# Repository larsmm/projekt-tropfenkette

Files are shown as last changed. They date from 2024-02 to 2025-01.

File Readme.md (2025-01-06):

# Welcome to Projekt Tropfenkette! ✨

A project featuring a box filled with 240 meters of ready-to-use LED strips to make events more colorful. These boxes are stored in hackerspaces or at the homes of beings. Coordination of which boxes are used at which events is done through a [Matrix group](https://matrix.to/#/#projekt-tropfenkette:matrix.warpzone.ms).

<table><tr>
<td><a href="https://www.youtube.com/watch?v=VafaI8VTRTc" target=new>My talk about this project at KampHack 2024 in warpzone hackerspace in Münster</a><br>
    <em>My talk about this project at <a href="https://kamphack.de/" target=new>KampHack 2024</a> in <a href="https://www.warpzone.ms/" target=new>warpzone</a> hackerspace in Münster (in german)</em></td>
</tr></table>

<br />

<table>

<tr>
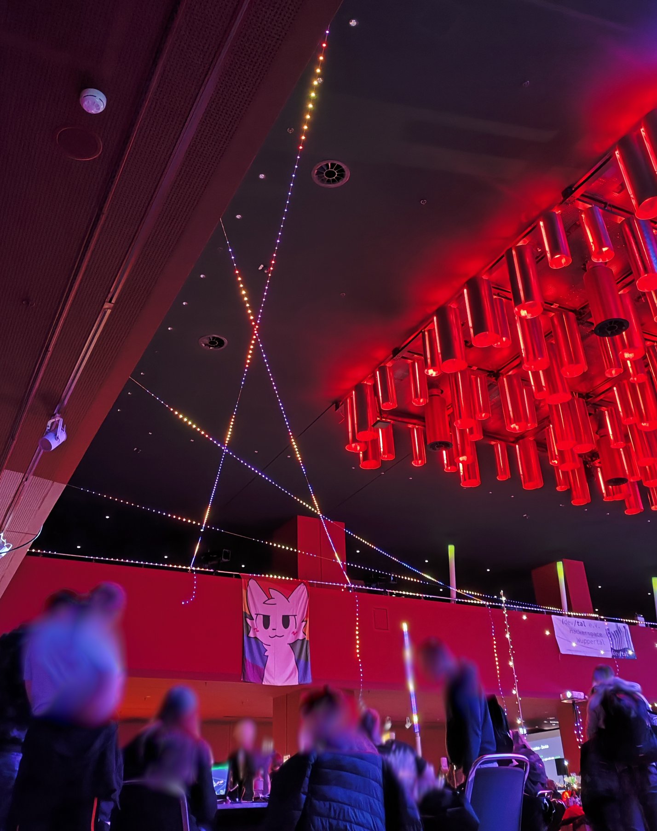
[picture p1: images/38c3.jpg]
<td> <a href="images/38c3.jpg"></a> </td>
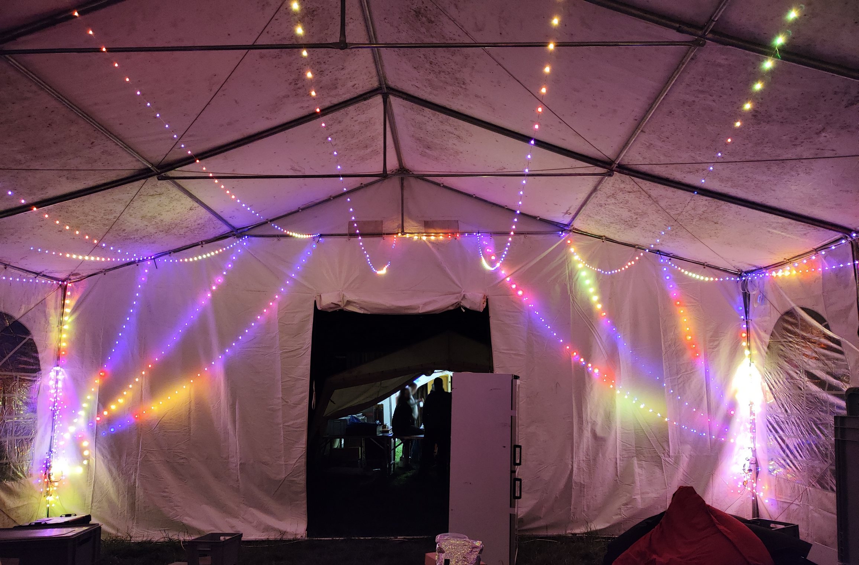
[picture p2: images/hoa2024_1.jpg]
<td>  </td>
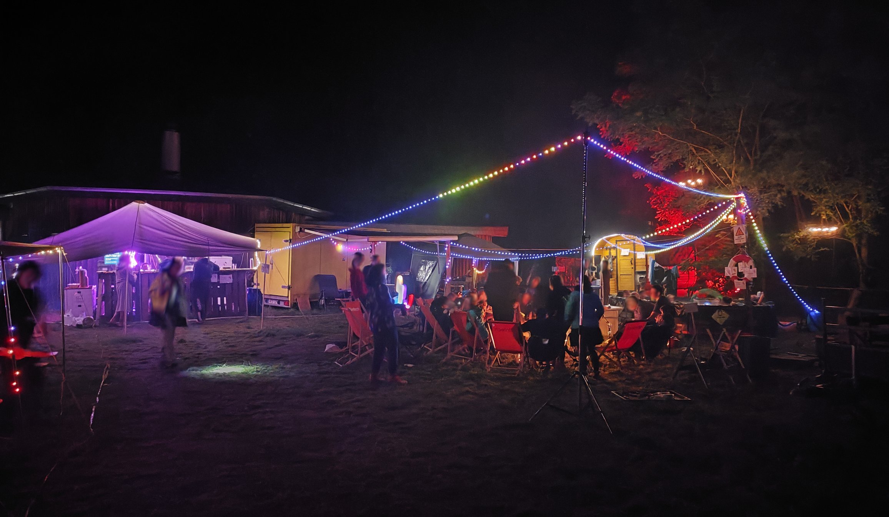
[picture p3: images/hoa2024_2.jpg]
<td>  </td>
</tr>

<tr>
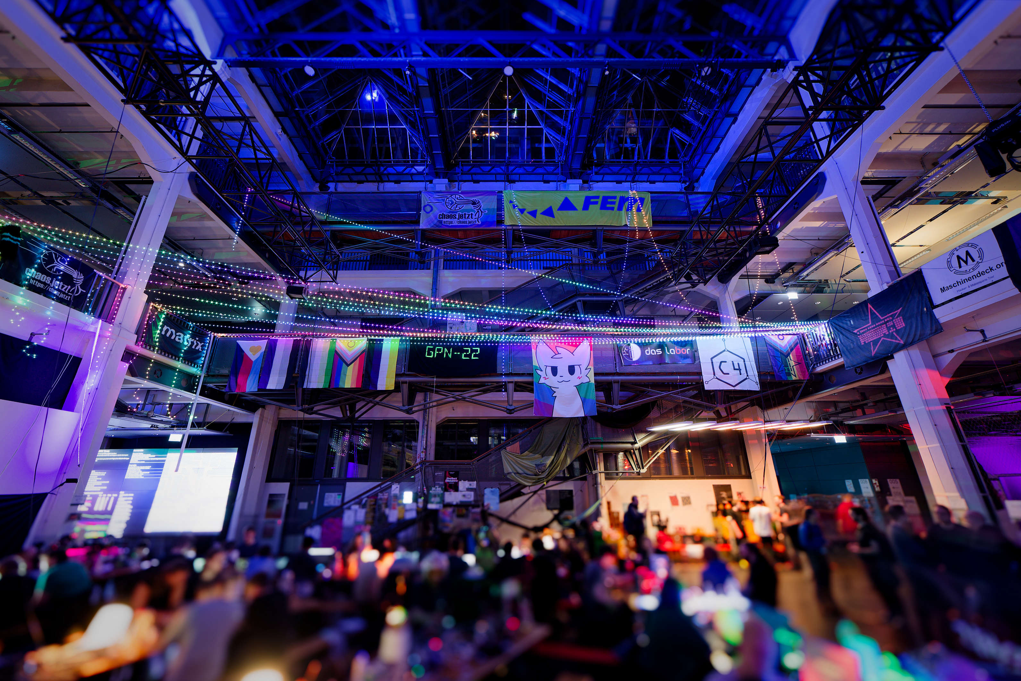
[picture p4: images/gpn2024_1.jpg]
<td>  </td>
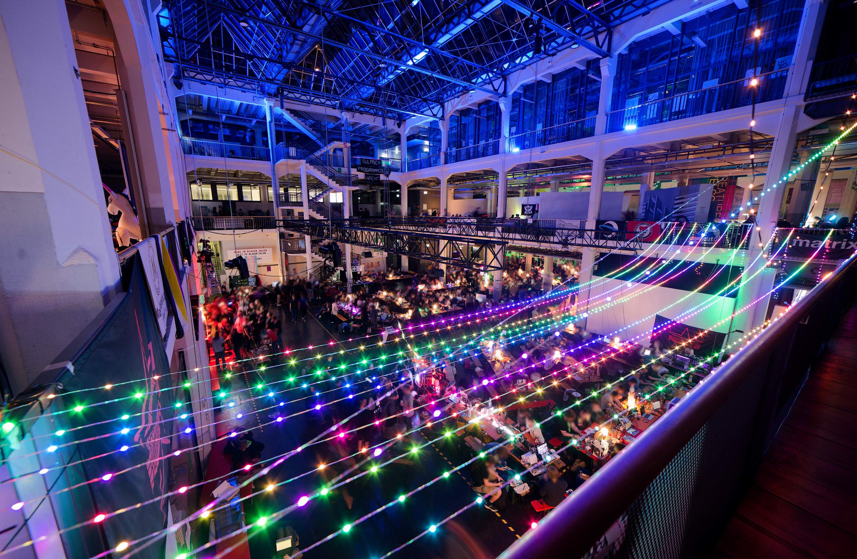
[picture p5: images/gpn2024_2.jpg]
<td>  </td>
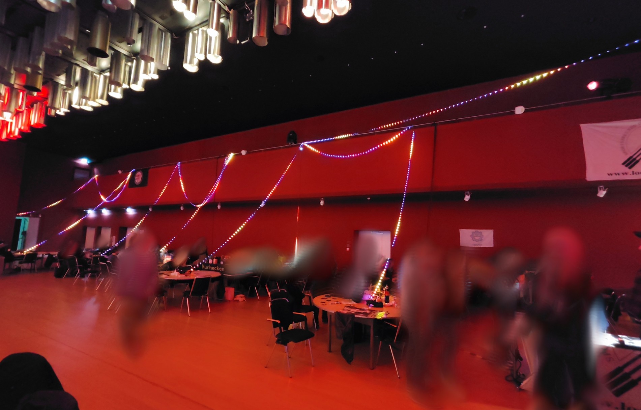
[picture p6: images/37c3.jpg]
<td>  </td>
</tr>

<tr>
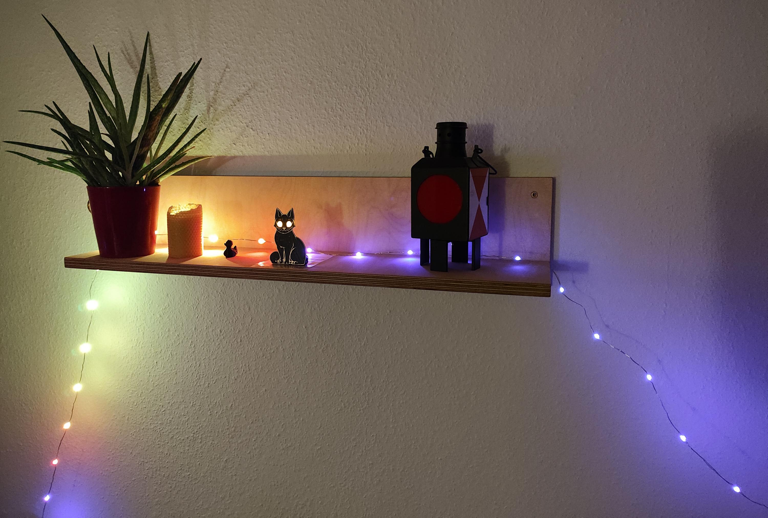
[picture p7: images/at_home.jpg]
<td>  </td>
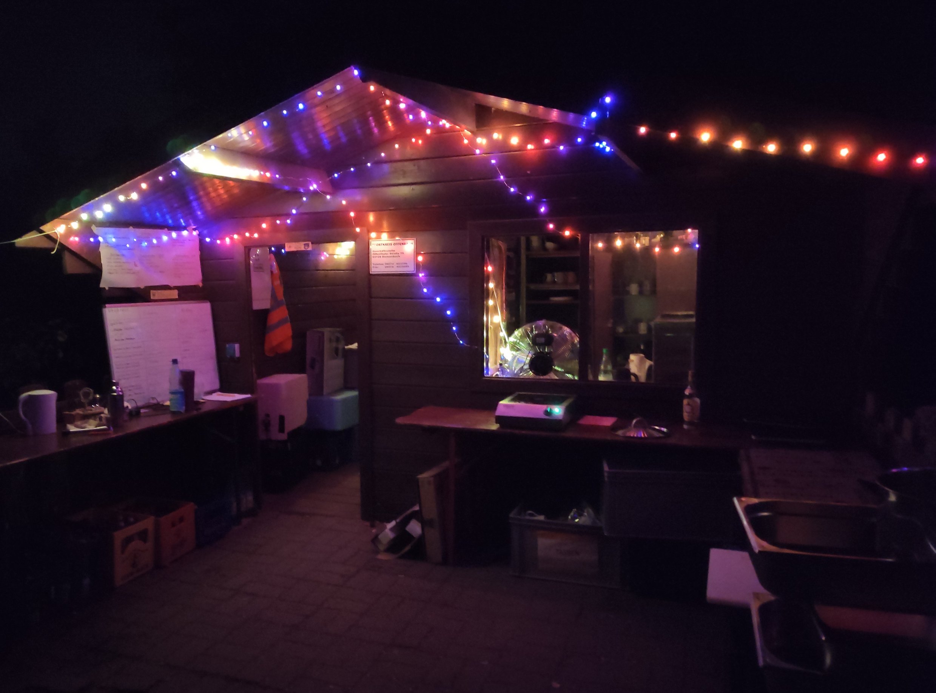
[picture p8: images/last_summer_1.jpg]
<td>  </td>
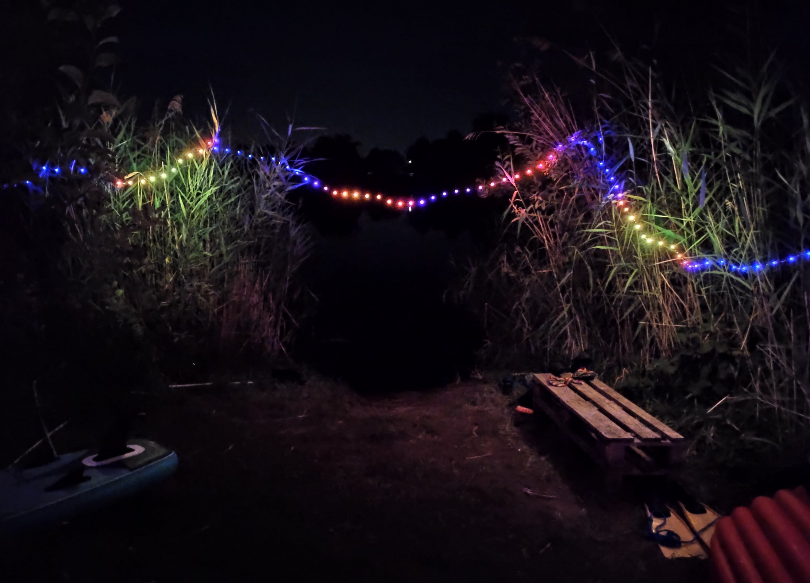
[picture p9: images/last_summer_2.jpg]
<td>  </td>
</tr>

<tr>
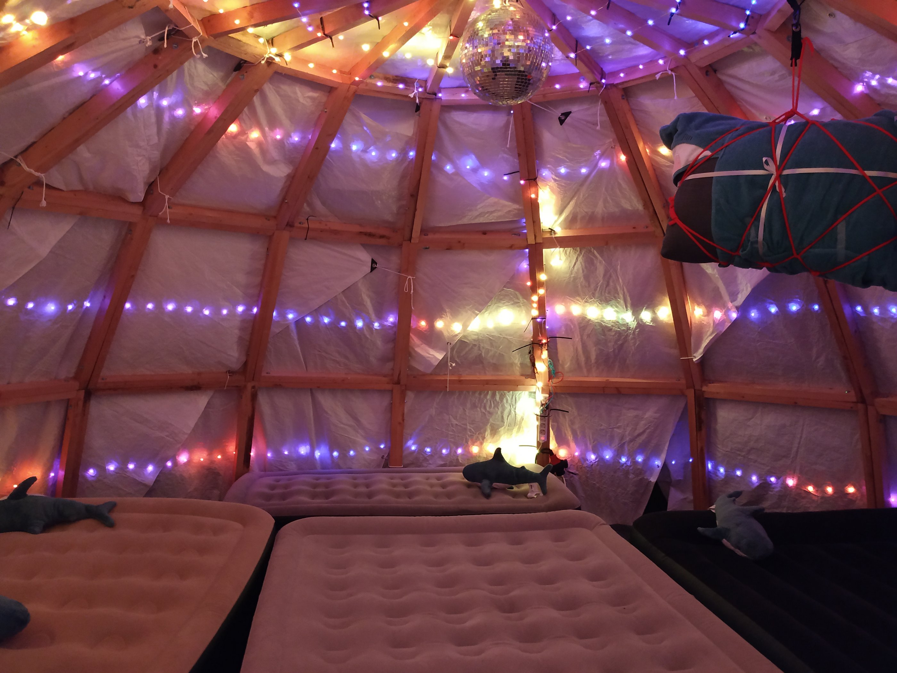
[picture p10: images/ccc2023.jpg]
<td>  </td>
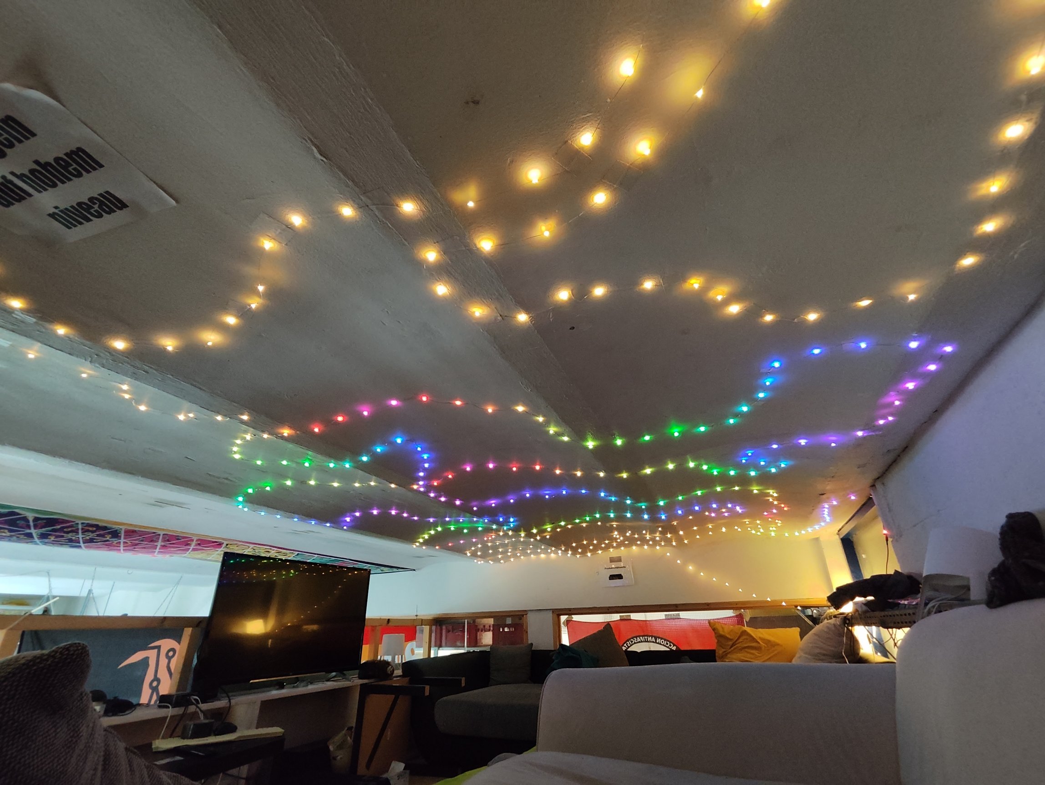
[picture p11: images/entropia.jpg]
<td>  </td>
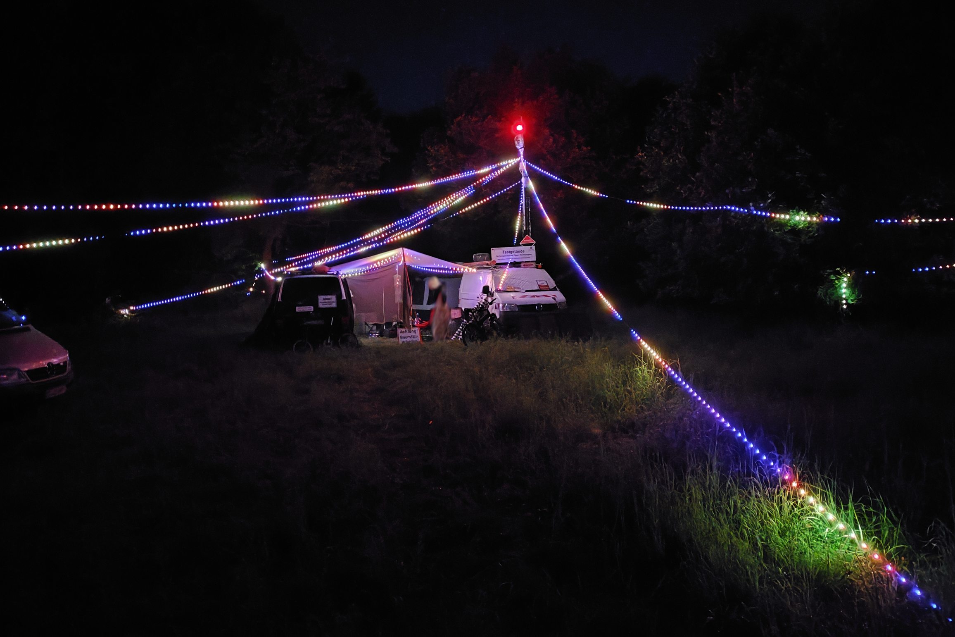
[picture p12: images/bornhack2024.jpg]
<td>  </td>
</tr>

<tr>
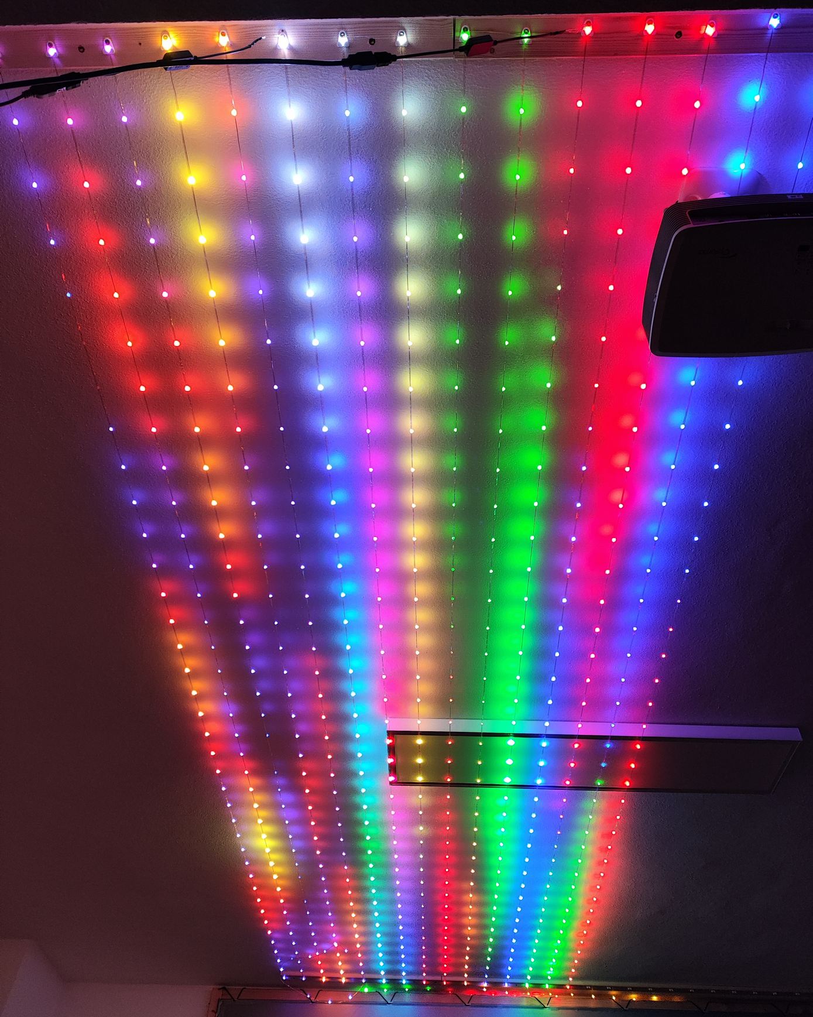
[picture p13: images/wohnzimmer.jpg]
<td> <a href="images/wohnzimmer.jpg"></a> </td>
<td>  </td>
<td>  </td>
</tr>

</table>

## Features

- Euro-box dimensions: 30 x 40 x 23 cm (or slightly smaller)
- 20m spools of LED Tropfenkette with 200 addressable RGB LEDs each + USB power supplies
- 3D-printed spools compatible with a power drill adapter
- WLED firmware on an ESP32 microcontroller
- User-friendly web interface
- WiFi and optional Ethernet with PoE support
- All information, instructions, and a service manual available in this Git repository
- A label on the box providing links to this Git repository and the [Matrix group](https://matrix.to/#/#projekt-tropfenkette:matrix.warpzone.ms)
- Each piece is labeled with a "Project Tropfenkette" sticker
- A [Matrix group](https://matrix.to/#/#projekt-tropfenkette:matrix.warpzone.ms) for coordinating the use of the boxes

## Contents of Each Box

<table><tr>
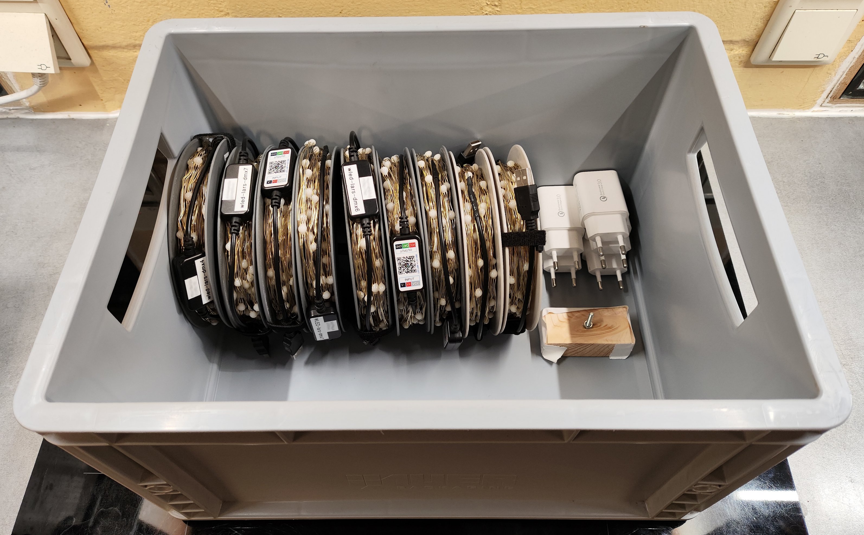
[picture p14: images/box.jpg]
<td>  </td>
</tr></table>

- 12 LED spools
- 12 WLED controllers
- 18 USB power supplies (to power some strips from both ends)
- 2 power drill adapters
- A bag of reusable cable ties
- 6 hook magnets (maybe)
- 2 spare controllers
- 2 empty spare spools
- Project Tropfenkette stickers
- A rubber duck

## LED Strip

20m long LED strips, available [here](https://www.aliexpress.com/item/1005003243510750.html), consisting of an addressable LED every 10cm on 3x magnet wire (enameled copper wire). Reasons why I really love these LEDs:

- Very high, not visible PWM frequency (non-flickering). Even when moving very fast in front of your eyes, it appears as a single line.
- Very good and intense colors, including a nice RGB-mixed white.
- Good omnidirectional light distribution.
- Very low idle current of 0.0125mA/LED, compared to other LEDs that need ~1mA.
- High ESD stability.

A disadvantage is the low mechanical durability due to being made of single stranded, thin insulated wires. However, with careful handling, they last many events and are quite easy to repair.

For most WLED effects, powering them from one side is sufficient. Plugs on both ends allow optional dual-side power. However, their brightness when powered from one side is moderate. For illumination purposes, you might need many strips or alternative solutions. Their true strength lies in creating a pleasant ambiance.

The strips are lightweight, enabling easy horizontal suspension over distances of 20m or 40m when connecting two strips end-to-end.

### Water Resistance

The strips are somewhat water-resistant. Exposure to rain or damp grass poses no issue. However, submersion beyond of more than ~3m of ledstrip may lead to erratic behavior due to high capacitance (as tested in a pool).

### Hardcoded Addresses

Unlike on most other strips, these LEDs are all connected in parallel, so each LED gets the same signal. That means, every LED has a hardcoded address. The low idle-current is a benefit of this. However, this means strips cannot be serially chained without duplicating control signals. For instance, if you connect two 200 LED strips in series, you still have the address range 1-200 instead of 1-400. If you activate one LED, the corresponding LEDs on both strips will light up. This requires careful planning for specific lighting designs. In this project, enery strip gets its own microcontroller pin.

## The Spool

The spool for winding the strip is 3D printed ([STL 1](stl/spool-1.stl), [STL 2](stl/spool-2.stl)) in two halves and then glued together. Currently, a simple wooden piece with an M5 screw serves as a makeshift power drill adapter. A 3D printed version has to be designed.

<table><tr>
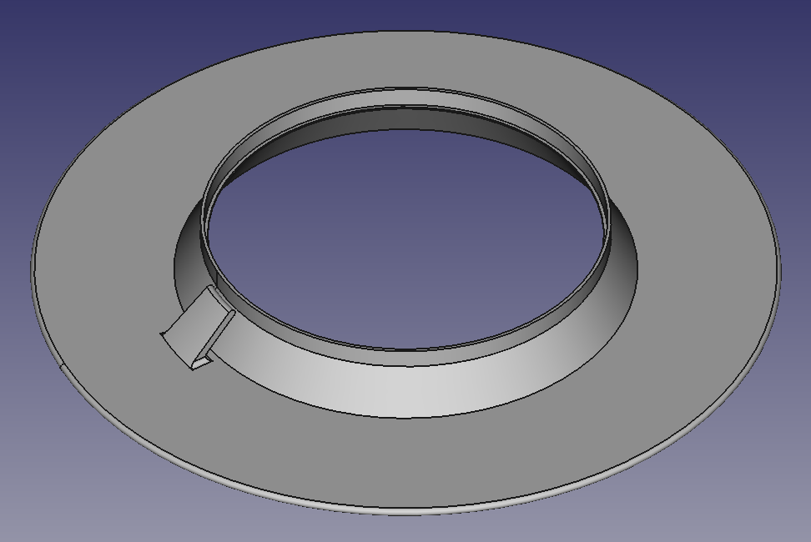
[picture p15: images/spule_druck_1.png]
<td>  </td>
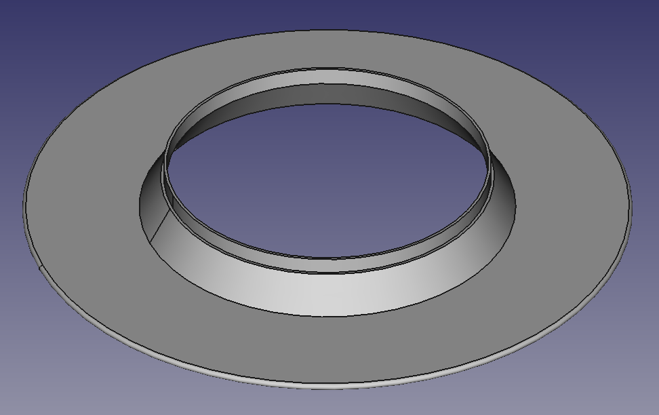
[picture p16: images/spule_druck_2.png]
<td>  </td>
</tr></table>
<table><tr>
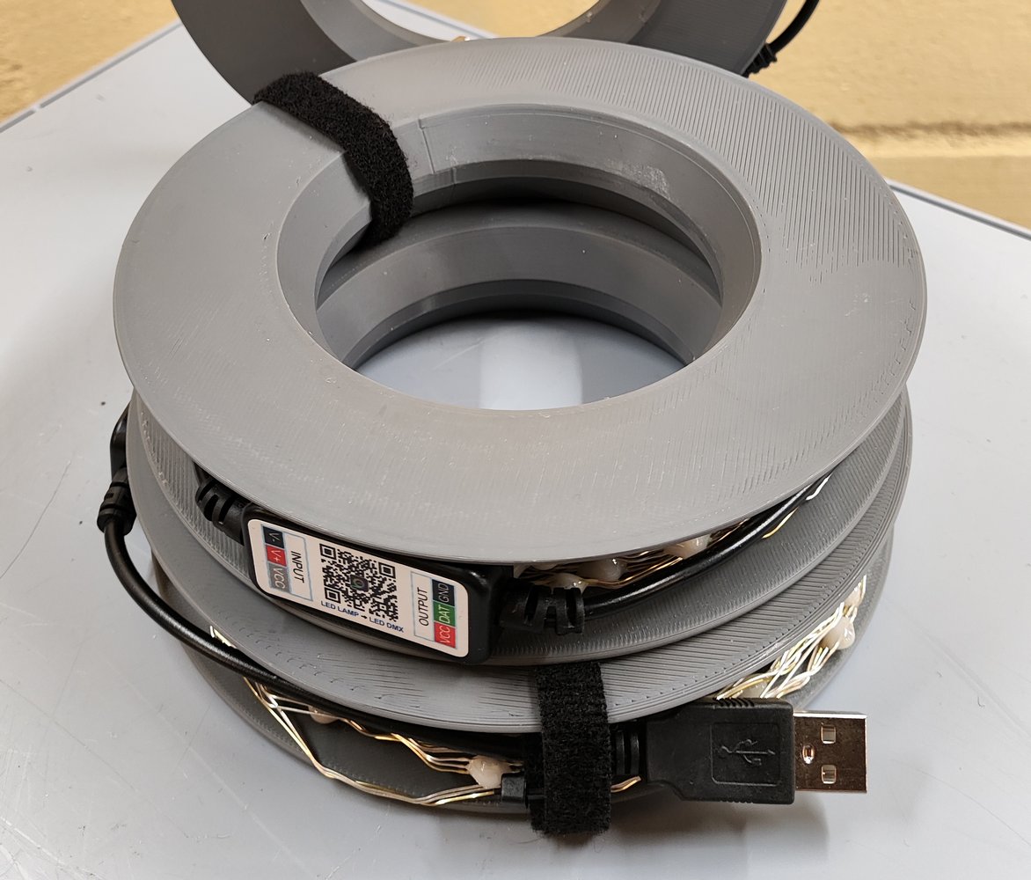
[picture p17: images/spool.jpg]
<td>  </td>
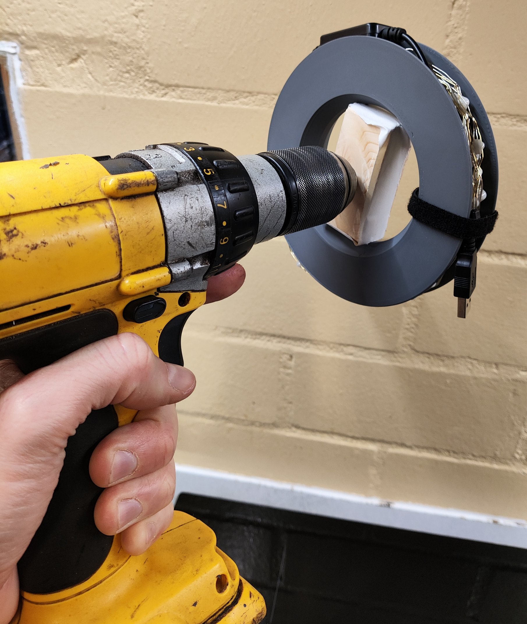
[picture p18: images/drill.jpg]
<td>  </td>
</tr></table>

## USB Power Supply

A simple 5V 3A [USB power supply](https://www.amazon.de/Ladeger%C3%A4t-Schnellladeger%C3%A4t-Ladestecker-Netzteil-Schnellladung-4er-Pack-Schwarz/dp/B0C3B7FL8Z). We tested (secutest) a few of them; they were safe. The power is sufficient, even if there is no current limit set in WLED. The wire resistance limits the current to ~2.3A.

## The Simple Controller with Standard Components

<table><tr>
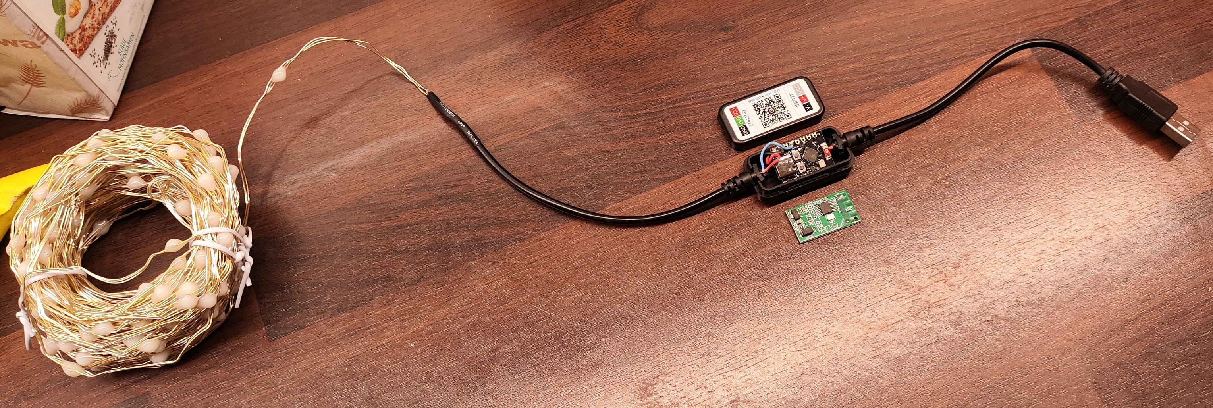
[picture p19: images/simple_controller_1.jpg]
<td>  </td>
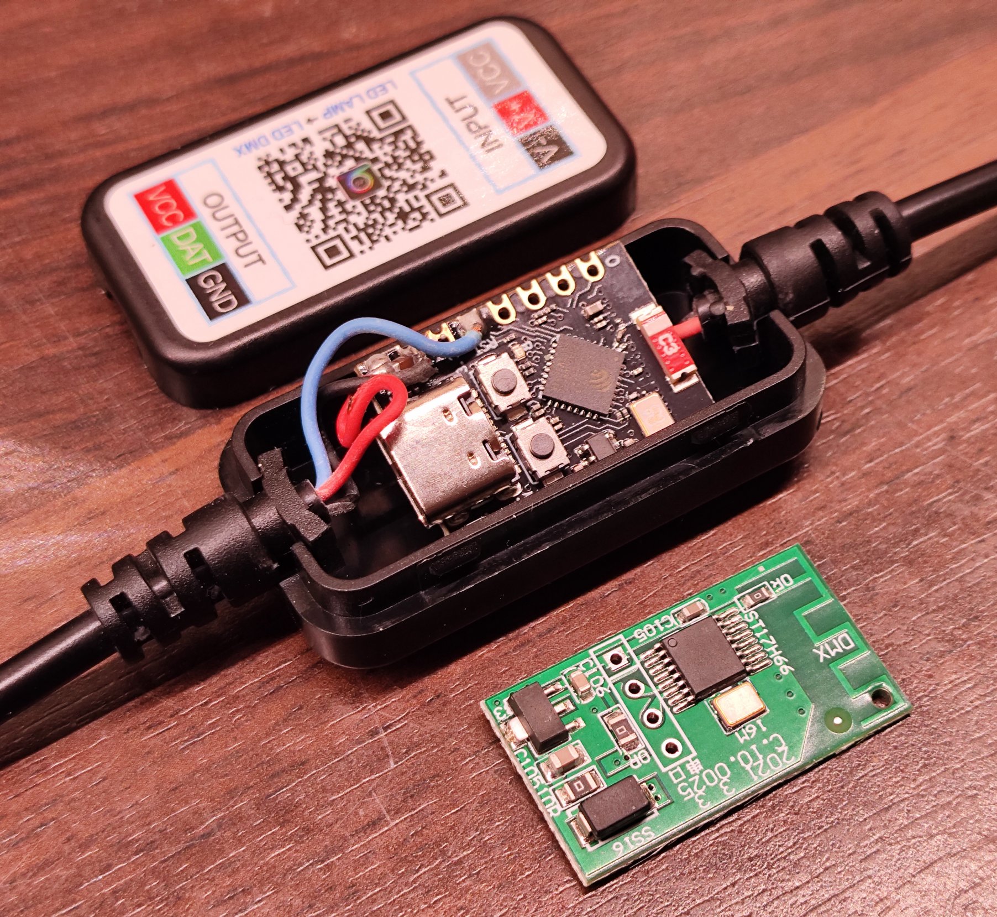
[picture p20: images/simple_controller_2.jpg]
<td>  </td>
</tr></table>

Ready to use [ESP32-C3-board](https://www.aliexpress.com/item/1005005967641936.html) with USB-C from AliExpress. Every 20m LED strip gets its own controller for convenience and because of the maximum current. The LED strips are shipped with a proprietary bluetooth controller, which gets replaced by our WLED controllers.

<table><tr>
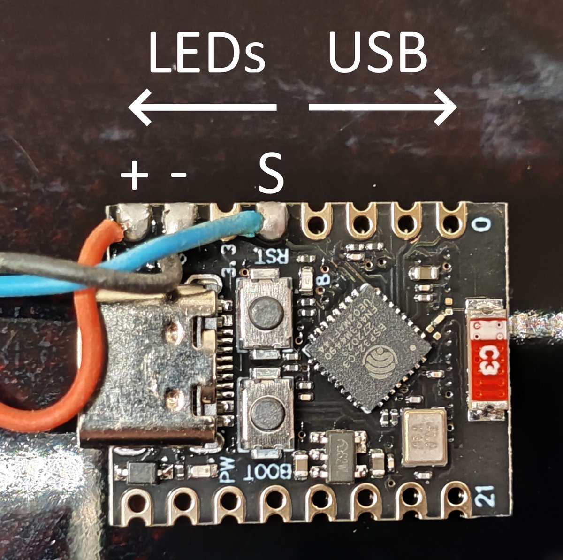
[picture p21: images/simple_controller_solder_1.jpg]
<td>  </td>
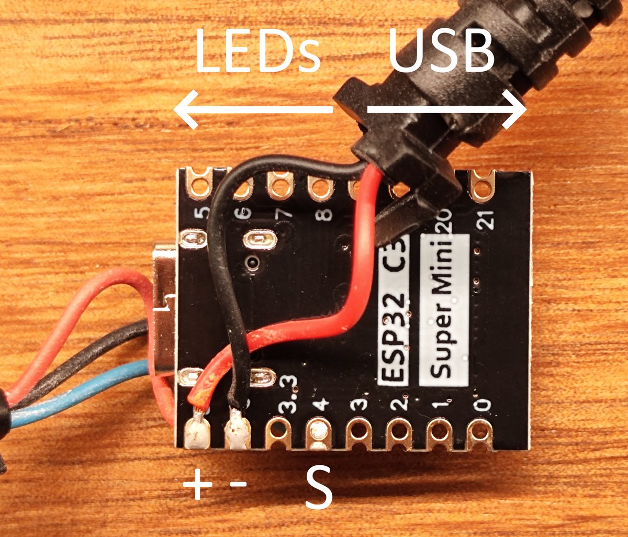
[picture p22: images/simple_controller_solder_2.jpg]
<td>  </td>
</tr></table>

How to solder:

- Open the case and unsolder the Bluetooth controller.
- Touch the wire ends of the LEDs with your soldering iron to make them pointy.
- Clamp the board somewhere, but be careful not to destroy the very small SMD parts.
- Put the 3 wires coming from the LEDs through the holes in the board and solder them with a bit of solder wire.
- Then solder the 2 USB-wires to the back of the board. Make sure to heat them up enough to get a good connection and short enough to not unsolder the LED-wires. The soldering points should be quite flat to fit into the case.

## Software

The strips are controlled by [WLED](https://kno.wled.ge/), firmware with many input options and a web interface to easily create nice effects. There are two common websites to flash WLED:

- The official one: <https://install.wled.me/> (Usually we use the newest build from here)
- And the fancy one: <https://wled-install.github.io/> (If you want more fancy features, use the nightly build)

Flash:

- Open the case and connect the ESP-Board via USB-C port, the USB-A plug is not for flashing!
- Open flash-page in a web-uart capable browser like chrome, choose the com port and the newest build of WLED.

Configuration:

- After flashing, connect to the `WLED-AP` Wifi. The landing page should open automatically. If not, enter <http://4.3.2.1> in your browser.
- TO THE CONTROLS! > Config > Security & Updates >
  - Restore presets: [choose file](cfg/wled_presets.json) > Upload
  - Restore configuration: [choose file](cfg/wled_cfg.json) > Upload
- The ESP will restart now. Now connect to Wifi again:
- WIFI SETTINGS > AP SSID: `WLED-[your name]-tk[number]`. For example `WLED-larsm-tk1`. Also write this name onto the controller-case.
- If you want to put the strips into an existing Wifi you can do so in Wifi Settings.
- The current limit in `LED Preferences` is not set because the wire resistance is limiting the current enough. Also, different limits were needed whether powering from one or both ends. It may result in strange looking effects by missing colors at the not powered end of the strip. Lower the brightness of the effect until it is ok.

### Default effect

WLED comes with many different effects and color schemes. The default effect is `Plasma` and the default color scheme is `Yelblu Hot` on full brightness. This is saved on Preset no 1 and loaded on boot. It is a slow, cosy effect using mostly yellow and orange but also a bit blue and purple. It sums up to a candle-like very warm white.

### Wifi name and PW

The SSID is printed on each controller-case `WLED-larsm-tk1`. The default PW is `wled1234`. This is a widely known PW. Please do only change it for a good reason and change it back after usage.

## Usage Guide

### Coordination

Utilize the [Matrix group](https://matrix.to/#/#projekt-tropfenkette:matrix.warpzone.ms) for coordination with hosts of other boxes. Ask them to bring boxes or offer your box.

For events involving larger installations, it's crucial to consult with the event organizers regarding **fire safety regulations (Brandschutz)** and **emergency exit routes (Fluchtwege)**.

### Use Cases

Choose your level of complexity:

1. **Simple Setup**: Unroll a few strips and power them via USB to enjoy the nice default effect.

2. **Intermediate**: Optionally, connect to the Wi-Fi printed on each controller (default password: `wled1234`). Access the web interface at <http://4.3.2.1> to customize effects.

3. **Advanced Synchronization**: WLED features an easy-to-use function for syncing effects across multiple controllers. Ensure they're connected to the same network via Wi-Fi or Ethernet.

4. **Professional-Level Control**: For granular control over every pixel across numerous strips in real-time, consider using Streaming ACN (sACN) over Ethernet.

## Help!!11!

**LED-strip broken:** please solder and insulate broken wires, ask for help in your local hackerspace and drink a mate.

**Controller broken:** Things you can try: connect to wifi, connect no or another ledstrip, reflash the controller. Use a multimeter and check voltages and currents.

**Something needs to be replaced or got lost:** It would be nice to keep this project alive by the awesome hacking community. So donations of replacement parts would be very welcome. If you, your fellow hackers or your hackerspace cannot afford it, please contact the [Matrix group](https://matrix.to/#/#projekt-tropfenkette:matrix.warpzone.ms).

## Two types of LEDs are sold :-(

These strips are sold with 2 kinds of LEDs on aliexpress which look the same on photos but with huge quality differences. Here a comparison:

| | Good strip | Bad strip |
|---|---|---|
| Protocol | default 3 wire WS28* | default 3 wire WS28* |
| LED type | custom nameless LED without extra plastic case within the glue drop | default WS2812B LED, you can see the quadratic case within the glue drop |
| PWM-frequency | very high == invisible | ~1-2Khz == flickering |
| Omnidirectional light distribution | noticeable but quite good | very noticeable |
| Quality of colors | nice | a bit less intense |
| Quality of RGB-mixed white | clean and nice white | unpleasant red tinge |
| Interconnection on the wires | parallel, each LED gehts the same signal, each LED has a hardcoded address | serial, default WS2812B LED with signal amplifier in each LED |
| Color of the wire (insolation) | a bit more copper-like | a bit more silver-like (not a huge difference, hard to tell on photos) |
| Idle-current [mA/LED] | 0,0125 | 0,50 |
| Current, white 50% [mA/LED] | 18,25 | 24,77 |
| Current, white 100% [mA/LED] | 35,45 | 42,93 |
| Digital color-order | RGB | GRB |
| Brightness | is hard to tell without measuring it | |
| Price | quite equal | |

So how to buy the good ones? There are a couple of dealers on aliexpress selling them. A good approach is to maintain a list of dealers and their offers, along with records of successful and unsuccessful purchases:

| good or bad | known good order | known bad order | Dealer | link | comment |
|---|---|---|---|---|---|
| ✅? | ~2023-11-20 | - | Aurboos LED Strip Store | [link](https://de.aliexpress.com/item/1005004753971048.html)  | Type: "Copper Wire"! The last known good order was quite a while ago. It's unclear if the good strip is still being delivered. Additionally, it has been out of stock for weeks. |
| ❌ | 2024-03-15 | 2024-06-03 | Mi Light Store | [link](https://www.aliexpress.com/item/1005003243510750.html) | It was a good source for a long time, but not anymore. I contacted the dealer. He said he could deliver the good strips, send me a test strip which was the bad one. :'( |
| ❌ | - | 2023-10-13 | LOAMLIN Official Store  | [link](https://www.aliexpress.com/item/1005001917228863.html) | Seller wrote 2023-11-14: the good ones are no longer available. |

As long as the strips are unavailible in Aurboos LED Strip Store the only source is Mi Light Store which is selling the bad strips. Don't get me wrong, but they are still good LED strips. I'm just very demanding.

Another thing: when ordering a 20m strip, you always get 2 10m pieces that are soldered together in the middle. In one delivery of the otherwise good strips, they were incorrectly addressed, namely 1-100 + 1-100 or 1-100 + 100-1 instead of 1-99 + 100-200. However, this only happened with one of many orders. Please test this upon arrival.

If something is not right, it is now very straightforward to return it on AliExpress. Simply click in the order overview, receive a shipping label, send it to a German address, and receive the refund within about a week.

## Bill of Materials - BOM

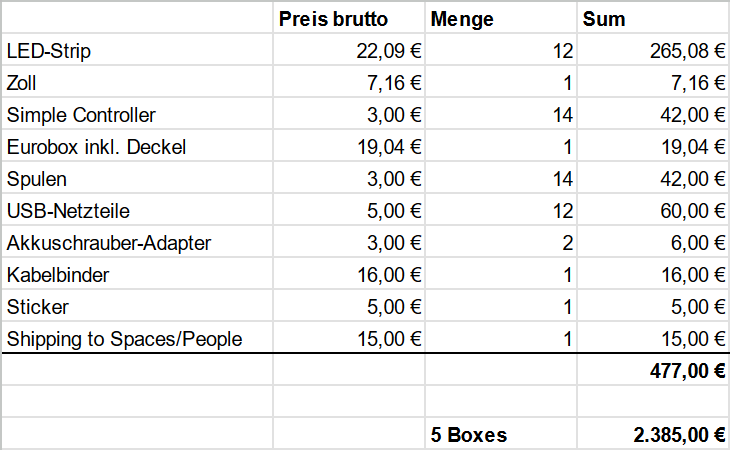
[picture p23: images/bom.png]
BOM (https://docs.google.com/spreadsheets/d/1PHROypnwYwpfAeiwreOVh2BaQhaZet9fSIjJTCfw_kE)


## The funding

The project, consisting of 5 boxes, is hoped to be financed by the CCC. For more details, refer to the [Projektantrag](Projektantrag.md).

## Vision

I would really love to see a lot of these LEDs on many future events! It would be great to see nearly all of them illuminating on next congress! :D

### The Advanced Controller with Custom Board

Vision: Custom WLED PCB with ESP32, microphone, and PoE. It can be used standalone or controlled via WiFi and powered by USB-C, or controlled and powered by Ethernet. If powered with more than USB 5V, more than 1 strip can be connected to 1 controller. Use the button on the PCB to switch through effects. I have already found some nice people who are definitely able to design this PCB, and they are hopefully willing to do it. :-)

### Microphone-Box

Vision: A small 3d-printed box with an [ESP32 board and a microphone](https://github.com/NandXor96/USBWLEDC) inside without LEDs. It can be used to control the audioreactive effects on the Tropfenketten. The network latency is quite high in WLED 0.15. We should wait for improvements.

### Other types of LEDs

Vision: Maybe the project will grow and other types of LEDfoo will spawn. For example the 2m long pipes wrapped with LED-Strip as seen on 37C3.

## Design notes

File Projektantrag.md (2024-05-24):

# Projektantrag zu Project Tropfenkette

Lieber CCC,

hiermit stelle ich einen Projektantrag für adressierbare RGB-LED-Lichterketten-Sets für chaosnahe Events. Jeweils 20m dieser Tropfenkette sind auf einer 3D gedruckten Spule aufgewickelt. 12 Spulen inkl. WLED-Controllern, Netzteilen und Montagematerial sind in einer Box zusammengefasst. Die Boxen werden in Hackspaces und deren Umfeld verteilt. Durch eine Matrix-Gruppe bleiben die Box-Holder in Kontakt und koordinieren den Einsatz auf Events. [Dieses GIT](Readme.md) bietet alle Informationen zur Nutzung und Instanthaltung des Projektes.

Einen Prototyp einer solchen Box war schon auf vielen Events im Einsatz, wo ich viel positives Feedback erhalten habe. Die bisher größten Installationen mit 200m waren auf dem 37C3 in einem der Hackcenter und auf der Esterhegg 2024 mit 320m. Um es größer zu skalieren, ist die Community gefragt, was ich in diesem Projektantrag verwirklichen möchte. Einige Wesen der warpzone in Münster und aus anderen Spaces konnte ich bereits für das Projekt begeistern und sie haben Hilfe angeboten.

Ich habe mit vielen Menschen aus dem Chaos über das Projekt gesprochen und viele Ideen mit einfließen lassen. Darunter auch Menschen, die etwas von Veranstaltungstechnik verstehen, Team Power und einigen Orga-Wesen auf dem 37C3. Ich habe Themen, wie Brandschutz, Fluchtwege und Sicherheit angesprochen. Solange man die Ketten nicht quer durch Fluchtwege hängt, gab es keine Bedenken. Auch elektrisch sind sie sicher, da sie nur mit 5V betrieben werden.

## Finanzierung

Die Kosten für eine Kiste belaufen sich auf ca. 480€, siehe [BOM](https://docs.google.com/spreadsheets/d/1PHROypnwYwpfAeiwreOVh2BaQhaZet9fSIjJTCfw_kE). Ggf lassen sich Rabatte nutzen, ggf ändern sich Preise und es wird teurer. Ich würde zur Sicherheit also 500€ pro Box einplanen. Ich würde mir wünschen, dass der CCC das Projekt finanziert. Die Anzahl der Kisten kann natürlich variiert werden.

## Umsetzung

Die Umsetzung bedeutet eine Menge Arbeit. Das Material muss bestellt, Spulen gedruckt, Controller gelötet, Firmware geflashed und Labels gedruckt werden, ...

### Bestellung

Das Meiste muss bei Aliexpress bestellt werden, ein Teil aus Deutschland. Vorschlag: Der CCC überweist mir einen Vorschuss von z. B. 2000€, ich tätige die Bestellungen. Wahrscheinlich lässt sich bei Aliexpress durch die Nutzung von Gutscheinen und Rabattaktionen einigs sparen. Das bedeutet allerdings, dass nicht alles auf einmal bestellt werden kann. Es wäre also ggf. sinnvoll, die Bestellungen über einige Wochen bis Monate zu strecken. Ggf. lässt sich auch ein Gesamtrabatt mit dem Händler aushandeln.

### Fertigung der Spulen und Akkuschrauber-Adapter

Mit ~150h Druckzeit (für 5 Kisten) bereitet der Druck der Spulen viel Aufwand. Hier hoffe ich auf Hilfe von Hackspaces und die Nutzung zahlreicher Drucker. Das Modell ist recht einfach zu drucken und sollte auf den meisten Druckern gut funktionieren. Mir steht ein Bambulanbs X1 Carbon Drucker zur Verfügung und ich könnte einen Teil der Spulen drucken.

### Löten und flashen der Controller

Das wird sich vorraussichtlich an ein paar Abenden mit ein Paar Leuten in der warpzone machen lassen.

### Zeitplan

Ich bin dabei mehr und mehr Wesen für das Projekt zu begeistern. Auf dem [KampHack 2024](https://kamphack.de) habe ich einen Talk dazu gehalten.

Ich denke, dass 2024 einige Boxen fertig werden könnten. Ich werde mittlerweile regelmäßig von Event-Orgas kontaktiert mit der Bitte um Verleih der Tropfenketten. Wie schnell sich das Projekt umsetzen lässt, hängt sehr davon ab, wieviel Hilfe ich erhalte.

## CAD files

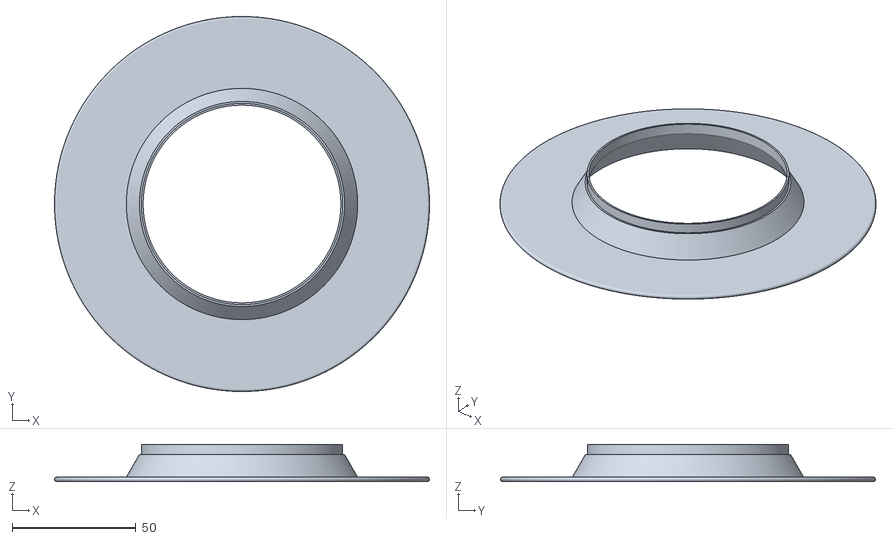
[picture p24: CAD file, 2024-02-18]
stl/spool-2.stl
151.8 x 151.8 x 15.0

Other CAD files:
stl/spool-1.stl

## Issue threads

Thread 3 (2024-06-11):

Awesome

fooker, 2024-06-11:
I just want to say thank you. :heart:

This project is so cool. I love the low cost, minimal effort.

While installing, I discovered a neat trick, I want to share: I've configured the wifi station and the wifi AP name to be the exact same on all device. So in an offline field installation,all devices will scan for this wifi when booted. The first powered device will fail at first and creates the wifi AP all other devices will connect to.

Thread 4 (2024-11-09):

2 little corrections for the README

CWempe, 2024-11-09:
Hi,
thanks for this great project!

I want to use this at home and just configured my first device.

But I found some thing that could be improved in the "Software" section of the README.

1.  "Configuration": You need the default WLED-AP-Password (`wled1234`) to connect to the Wifi after restoring the configuration..
2. "Default effect": The guide says "Plasma Yelblu Hot" (supposed to be Preset 1)  is set as default.
  But in my case Preset 1 is a demo with changes the effect every ~5s.
  I had to change the default boot preset to `18´ to use "Plasma Yelblu Hot".

Anyway.
Thank you again for pointing me to this nice hardware (LED stripes and ESP32-C3) and for the great guide.

CWempe, 2024-11-09:
btw: I use version 14.4 (beuacse it is stable.

But there might be an issue with saving configuration.
Actually I am not able to save a boot-preset.
So this might the cause for issue number 2.

I will try v15.

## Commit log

2024-02-18 initial commit :-)
    [spool-1.stl, spool-2.stl]
2024-03-28 greatly improved everything ;-) added wled configuration files, new pictures, soldering tutorial
2024-10-07 news about led sources, new pics
